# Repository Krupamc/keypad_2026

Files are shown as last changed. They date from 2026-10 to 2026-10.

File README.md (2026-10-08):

# My Linux-looking Macropad
The name is a work in progress I know haha. This is my macropad, a small custom shortcut pad with several layers of shortcuts that are changed through the rotary encoder. Different LEDs light up and the OLED with update with the current layer and appropriate image. I created this in order to increase my productivity and overall workflow of my desk.
---

## Features:
- 128x32 OLED Display for customized layer imagary
- EC11 Rotary encoder to switch between layers.
- 5 Layer LEDs to coordinate with the layers (will activate one by one and change colors; layer 0 has 1 navy blue LEDs, layer 1 has 2 dark blue LEDs).
  - (Colors are customizable) 
- 4 Keys
- 1 Status/Ambient LED
- Being a really cool thing to flex.
---
## PCB:
The PCB (Printed Circuit Board) was created using KiCad. Awesome open source software.
You can open the PCB here:


### Schematic: 

Here is the plan for the PCB laid out with my wiring.

### PCB:


Very cool looking PCB. I added as much silkscreen I could to really sell the terminal-inspired design.

## CAD:

I created a case in Fusion. Excuse how it is not very good/original as it is my first time doing CAD before. I have two parts: the bottom and top case. 
### Bottom Case:
The bottom case is a box with standoffs to hold (on the top-right, and bottom-left) the PCB. M3x16mm screws go through the screw holes on the bottom through the standoffs. The bottom case also has a single foot that has a 40° angle for one inch. (same as my current keyboard to be consistant) The foot has small circle indents for rubber feet in future or hot glue. There is also a USB-C cutout for the microcontroller 

### Top Case:  
This section has extrusions for heat inserts to go (for the screws mentioned before) as well as holes for the OLED, LEDs, keys, and the rotary encoder.




---

## Firmware Functions:
Coded in KMK (Micro-python based keyboard framework). On each layer, a configurable photo, text splash and color (for LEDs) is shown. The number of LEDs active is based on the layer number.

Right now the short cuts include:
- Copy, Paste, Undo, Redo
- CTRL + F, clipboard, File explorer, Screenshots
- Pause unpause, mute discord mic, defen discord, mute pc

Planned to add ones for games I play/other applications later.

---

## BOM:
- 1X Seeed XIAO RP2040
- 1x 0.91" 128x32 OLED Display
- 4x Cherry MX Switches
- 4x DSA Keycaps
- 1x EC11E Rotary encoders
- 6x SK6812 MINI-E LEDs
- 2x M3x16mm screws
- 2x M3x5mx4mm heatset inserts
- 3x Parts for 3D Case (Top, Bottom, and Knob).

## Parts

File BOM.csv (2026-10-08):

Item | Quantity
Seeed XIAO RP2040 | 1
0.91" 128x32 OLED Display | 1
Cherry MX Switches | 4
DSA Keycaps | 4
EC11E Rotary encoders | 1
SK6812 MINI-E LEDs | 6
M3x16mm screws | 2
M3x5mx4mm heatset inserts | 2
Parts for 3D Case (Top, Bottom, and Knob). | 1

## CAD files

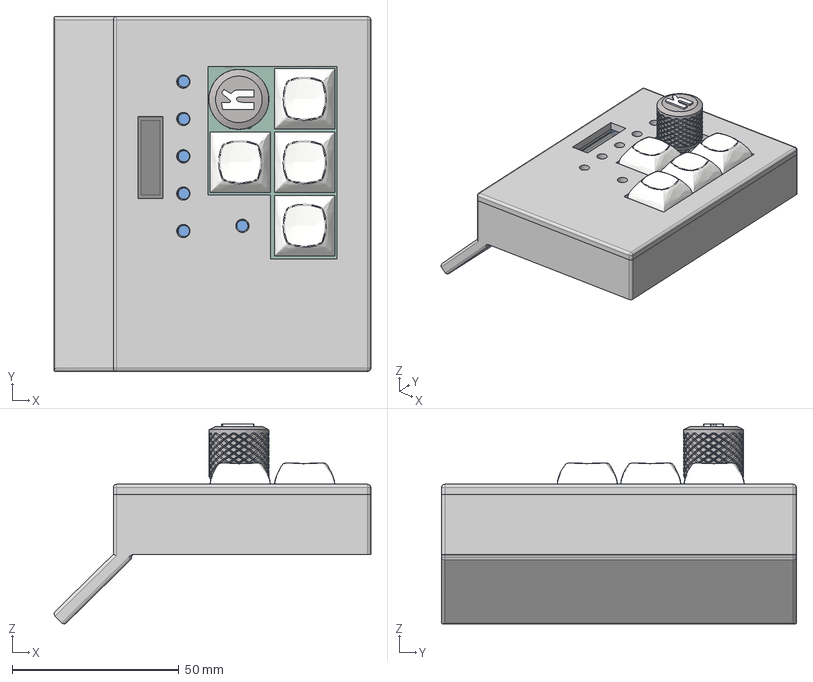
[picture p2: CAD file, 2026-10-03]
CAD/hackpad_full.step
94.9 x 106.3 x 59.8 mm
base v6
type-c v2
smd_button v3
DOUT
DIN
VSS
VDD
smd_button v3(Mirror)
MX Öá °´¼ü¡ä_¨¹ ___¡§1 x 4
MX Öá ÖáÌå¨¢¨¬ _¡§¡é¡§__ x 4
MXÖá ÖáÌå µ×²¿ ¦Ì¡ Á2__Ä¬ÈÏ_¨¢2____¨¨_ x 4
Õë½Å___Ä¬ÈÏ__¨¨ _ x 4
Ðý×ª±àÂëÆ÷
PinHeader_1x04_P254mm_Vertical
hackpad_copper
hackpad_pad
hackpad_via
hackpad_silkscreen
hackpad_silkscreen_1
hackpad_soldermask
hackpad_soldermask_1
hackpad_PCB
LED_WS2812B_PLCC4_50x50mm_P32mm x 6
0.91in oled Module - Board
0.91in OLED - Folded Flush - Without Glass
0603 Capacitor x 9
0603 Resistor x 5
SOT23-3
Diode (SOD-323)
MX Mount v1 x 4
Base
M3x12 SHCS x 2
Keypad
M3 Threaded Insert x 2

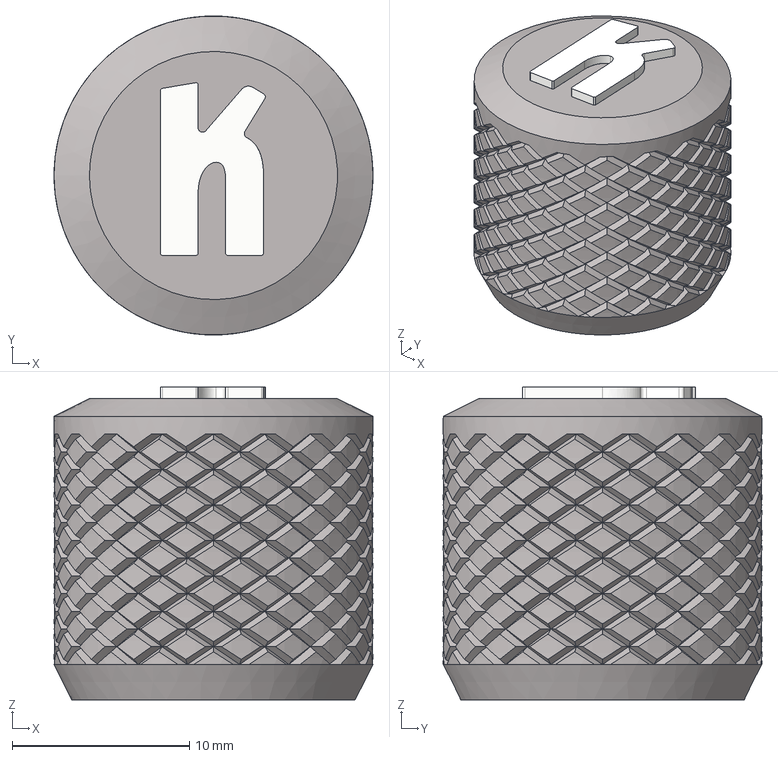
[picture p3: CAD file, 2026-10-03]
production/KNOB.step
18.0 x 18.0 x 17.6 mm
Base
H

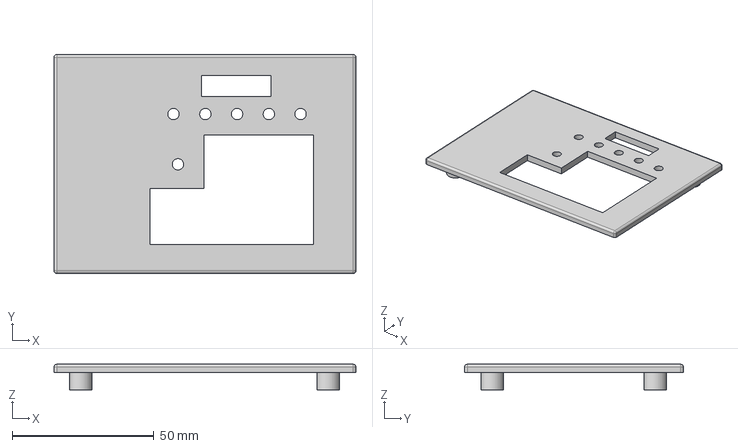
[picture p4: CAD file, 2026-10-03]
production/TOP.step
106.3 x 77.2 x 9.00 mm

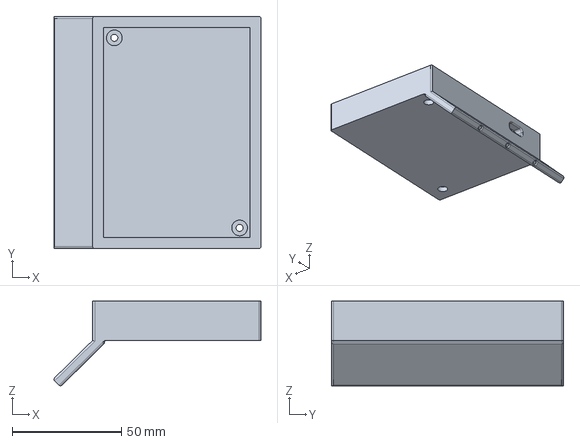
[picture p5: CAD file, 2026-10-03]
production/BOTTOM.step
94.9 x 106.3 x 38.8 mm

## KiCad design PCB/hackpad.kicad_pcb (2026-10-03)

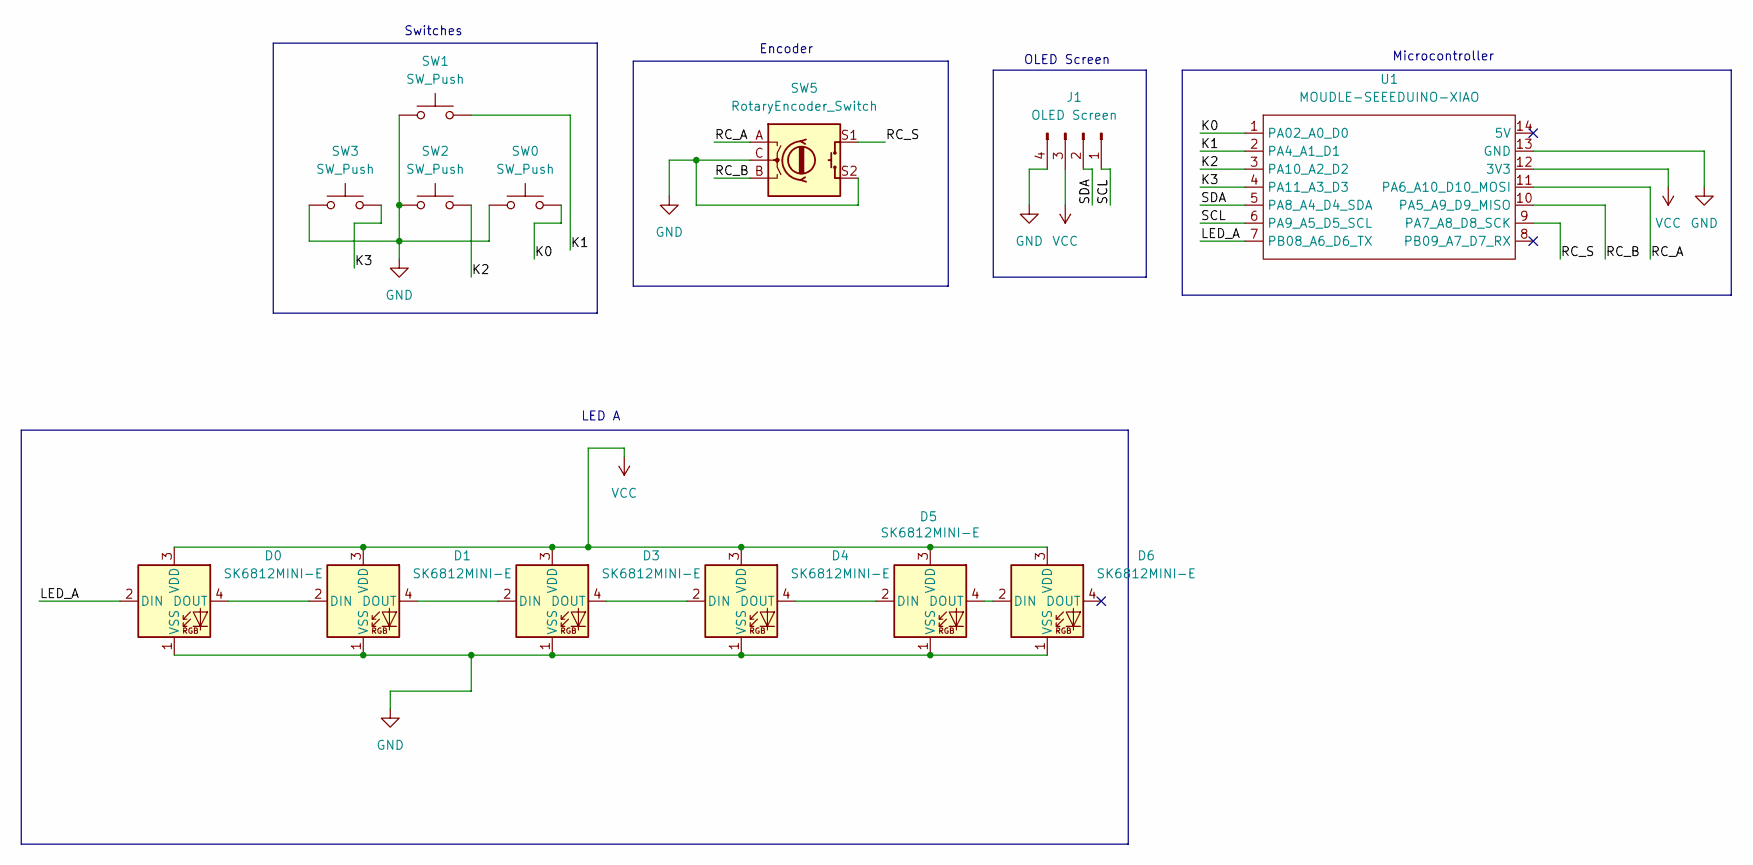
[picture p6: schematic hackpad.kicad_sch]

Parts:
D0, D1, D3, D4, D5, D6: SK6812MINI-E; LED_OPSCO_SK6812_PLCC4_5.0x5.0mm_P3.1mm
J1: OLED Screen; PinHeader_1x04_P2.54mm_Vertical
SW0, SW1, SW2, SW3: SW_Push; SW_Cherry_MX_1.00u_PCB
SW5: RotaryEncoder_Switch; RotaryEncoder_Alps_EC11E-Switch_Vertical_H20mm
U1: MOUDLE-SEEEDUINO-XIAO; XIAO-Generic-Hybrid-14P-2.54-21X17.8MM

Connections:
/K0: SW0.2, U1.1 (PA02_A0_D0)
/K1: SW1.2, U1.2 (PA4_A1_D1)
/K2: SW2.2, U1.3 (PA10_A2_D2)
/K3: SW3.2, U1.4 (PA11_A3_D3)
/LED_A: D0.2 (DIN), U1.7 (PB08_A6_D6_TX)
/RC_A: SW5.A, U1.11 (PA6_A10_D10_MOSI)
/RC_B: SW5.B, U1.10 (PA5_A9_D9_MISO)
/RC_S: SW5.S1, U1.9 (PA7_A8_D8_SCK)
/SCL: J1.1, U1.6 (PA9_A5_D5_SCL)
/SDA: J1.2, U1.5 (PA8_A4_D4_SDA)
GND: D0.1 (VSS), D1.1 (VSS), D3.1 (VSS), D4.1 (VSS), D5.1 (VSS), D6.1 (VSS), J1.4, SW0.1, SW1.1, SW2.1, SW3.1, SW5.C, SW5.S2, U1.13 (GND)
unnamed: D0.4 (DOUT), D1.2 (DIN)
unnamed: D1.4 (DOUT), D3.2 (DIN)
unnamed: D3.4 (DOUT), D4.2 (DIN)
unnamed: D4.4 (DOUT), D5.2 (DIN)
unnamed: D5.4 (DOUT), D6.2 (DIN)
VCC: D0.3 (VDD), D1.3 (VDD), D3.3 (VDD), D4.3 (VDD), D5.3 (VDD), D6.3 (VDD), J1.3, U1.12 (3V3)

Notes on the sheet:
Microcontroller
Switches
OLED Screen
Encoder
LED A

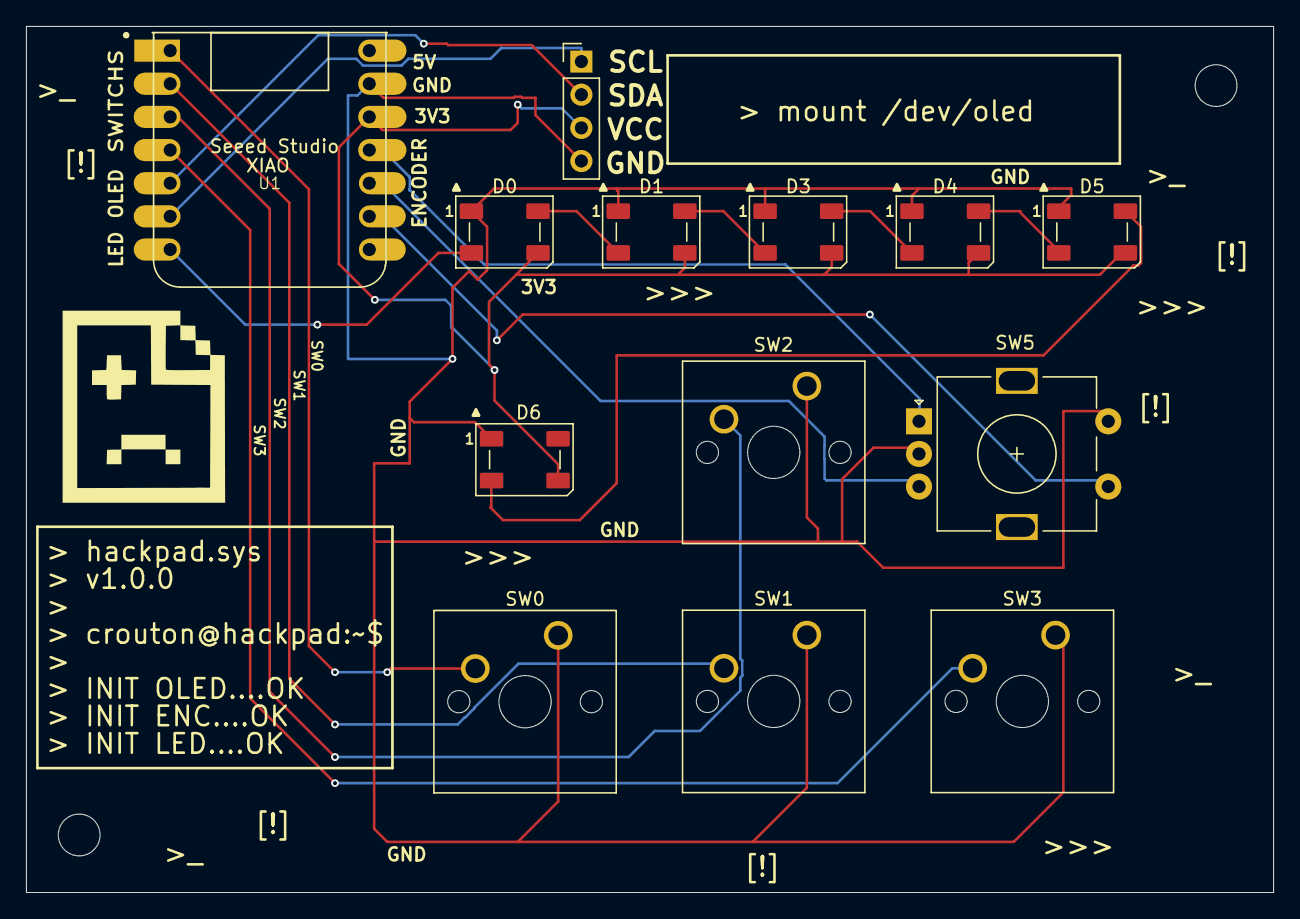
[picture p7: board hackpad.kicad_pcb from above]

Board: 2 copper layers, 95.5 x 66.4 mm, 13 parts (0 on the bottom side), 17 nets.

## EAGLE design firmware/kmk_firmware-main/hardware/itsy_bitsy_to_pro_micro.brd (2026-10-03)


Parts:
FRAME2: FRAME-LETTER; CREATIVE_COMMONS
JP1: HEADER-1X570MIL; 1X05_ROUND_70
JP2, JP4: HEADER-1X14; 1X14_ROUND70
JP3, JP5: M12PTH; 1X12

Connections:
!RESET: JP3.3, JP4.14
+3V3: JP4.13
A0: JP3.5, JP4.10
A1: JP3.6, JP4.9
A2: JP3.7, JP4.8
A3: JP3.8, JP4.7
A4: JP3.9, JP4.6
A5: JP3.10, JP4.5
AREF: JP4.12
D2: JP4.1
D3: JP1.4
D4: JP1.5
D5_5V: JP2.10
D7: JP2.9, JP5.1
D9: JP2.8, JP5.2
D10: JP2.7, JP5.3
D11: JP2.6, JP5.4
D12: JP2.5, JP5.5
D13: JP2.4, JP5.6
EN: JP1.1
GND: JP2.2, JP3.2, JP5.9, JP5.10
MISO: JP4.2
MOSI: JP3.12, JP4.3
RAW_PM: JP3.1
RX_D0: JP2.14, JP5.11
SCK: JP3.11, JP4.4
SCL: JP2.11, JP5.7
SDA: JP2.12, JP5.8
SWCLK: JP1.3
SWDIO: JP1.2
TX_D1: JP2.13, JP5.12
VBAT: JP2.1
VBUS: JP2.3, JP3.4
VHI: JP4.11

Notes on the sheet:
TX0/PD3->TX RX1/PD2->RX GND->GND GND->GND 2/PD1->SDA 3/PD0->SCL 4/PD4->13 5/PC6->12 6/PD7->11 7/PE6->10 8/PB4->9 9/PB5->7
OLD
Raw-> GND->GND RST->RST VCC->USB A3/PF4->A0 A2/PF5->A1 A1/PF6->A2 A0/PF7->A3 15/PB1->A4 14/PB3->A5 16/PB2->SCK 10/PB6->MOSI
Bryan Siepert



Board: 2 copper layers, 35.8 x 20.7 mm, 6 parts (2 on the bottom side), 21 nets.

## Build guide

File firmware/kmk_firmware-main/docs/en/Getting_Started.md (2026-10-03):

# Getting Started
> Life was like a box of chocolates. You never know what you're gonna get.

KMK is a keyboard focused layer that sits on top of [CircuitPython](https://circuitpython.org/). As such, it should work with most [boards that support CircuitPython](https://circuitpython.org/downloads). KMK requires CircuitPython version 7.3 or above.
Known working and recommended devices can be found in the [list of officially supported microcontrollers](Officially_Supported_Microcontrollers.md)

## TL;DR Quick start guide
> To infinity and beyond!
1. [Install CircuitPython version 7.3 or higher on your board](https://learn.adafruit.com/welcome-to-circuitpython/installing-circuitpython). With most boards, it should be as easy as drag and dropping the firmware on the drive
2. Get an up to date [copy of KMK](https://github.com/KMKfw/kmk_firmware/archive/refs/heads/main.zip) from the main branch 
3. Unzip it and copy the KMK folder and the boot.py file at the root of the USB drive corresponding to your board (often appearing as CIRCUITPY)
4. Create a new *code.py* or *main.py* file in the same root directory (same level as boot.py) with the example content hereunder: 

***IMPORTANT:*** adapt the GP0 / GP1 pins to your specific board !

```
print("Starting")

import board

from kmk.kmk_keyboard import KMKKeyboard
from kmk.keys import KC
from kmk.scanners import DiodeOrientation

keyboard = KMKKeyboard()

keyboard.col_pins = (board.GP0,)
keyboard.row_pins = (board.GP1,)
keyboard.diode_orientation = DiodeOrientation.COL2ROW

keyboard.keymap = [
    [KC.A,]
]

if __name__ == '__main__':
    keyboard.go()
```

5. With a wire / paperclip / whatever, connect the pins you selected for col_pin and row_pin together.

feather and keeboar example pins


6. If it prints the letter "a" (or a "Q" or ... depending on your keyboard layout), you're done!

## Now that you're up and running, you may want to go further...
> This is your last chance. After this, there is no turning back. You take the blue pill—the story ends, you wake up in your bed and believe whatever you want to believe. You take the red pill—you stay in Wonderland, and I show you how deep the rabbit hole goes. Remember: all I'm offering is the truth. Nothing more.

### You're extremely lucky and you have a fully supported keyboard
If your keyboard and microcontroller are officially supported, simply visit the page for your files, and dropping them on the root of the "flash drive".
Those pages can be found in the repositories [boards folder](https://github.com/KMKfw/kmk_firmware/tree/master/boards).
You will need the `kb.py` and `main.py`. If you need more detailed instructions on how to customize the configuration settings and key mappings, please refer to the [config and keymap](config_and_keymap.md) documentation.

### You've got another, maybe DIY, board and want to customize KMK for it  
First, be sure to understand how your device work, and particularly its specific matrix configuration. You can have a look at [how key matrices work](http://pcbheaven.com/wikipages/How_Key_Matrices_Works/) or read the [guide](https://docs.qmk.fm/#/hand_wire) provided by the QMK team for handwired keyboards
Once you've got the gist of it:
- To start customizing your `code.py`/`main.py` file, please refer to the [config and keymap](config_and_keymap.md) and [keys](keys.md) files respectively, which provide detailed instructions on how to modify the configuration settings and key mappings.
- There's a [reference](keycodes.md) of the available keycodes
- [International](international.md) extension adds keys for non US layouts and [Media Keys](media_keys.md) adds keys for ... media

And to go even further:
- [Macros](macros.md) are used for sending multiple keystrokes in a single action
- [Layers](layers.md) can transform the whole way your keyboard is behaving with a single touch
- [HoldTap](holdtap.md) allow you to customize the way a key behaves whether it is tapped or hold, and [TapDance](tapdance.md) depending on the number of times it is pressed

Want to have fun features such as RGB, split keyboards and more? Check out what builtin [modules](modules.md) and [extensions](extensions.md) can do!
You can also get ideas from the various [user examples](https://github.com/KMKfw/kmk_firmware/tree/master/user_keymaps) that we provide and dig into our [documentation](README.md).

### Pre-compiling KMK for faster boot times or microcontrollers with limited flash

There are two options:
1. To compile KMK yourself you'll need to download and install the [compatible mpy-cross](https://adafruit-circuit-python.s3.amazonaws.com/index.html?prefix=bin/mpy-cross/)
  for your Operating System. Don't forget to add it to your PATH, test by running `mpy-cross` from a shell (Powershell, Bash, Fish, etc). Once that's set up, run either `make compile` (if you have `make`) or `python util/compile.py`to generate the `.mpy` versions of KMK files. Then copy the whole compiled `kmk/` directory to your keyboard.

There are even more compile and copy make targets.
Power user can compile KMK and additional libraries, and then load the bytecode and keyboard code
onto a keyboard in one go:
```sh
make compile copy-compiled copy-board MPY_SOURCES='kmk/ lib/' BOARD='boards/someboard' MOUNTPOINT='/media/user/someboard'
```

2. To download a pre-compiled KMK go to [Actions > Build on the KMK GitHub project page](https://github.com/KMKfw/kmk_firmware/actions/workflows/compile.yml),
  click on the latest build, and you'll find the download link at the bottom of the page under Artifacts. Unzip the download and place the contents in the `kmk/` directory on your keyboard.

On certain microcontrollers that will still not be enough of a size reduction to
fit all of KMK onto the flash (nice!nano for example).
You can remove any optional parts of KMK you aren't using.
Start by skipping `kmk/extensions`, `kmk/modules`, and `kmk/quickpin` and adding in only the files under those paths used in your keyboard (i.e. files that are imported in your `main.py` or `kb.py`).

## Additional help and support
> Roads? Where we're going we don't need roads.

In case you need it, debugging help can be found on the [debugging](debugging.md) page.

For asynchronous support and chatter about KMK, [join our Zulip
community](https://kmkfw.zulipchat.com)!

If you ask for help in chat or open a bug report, if possible
make sure your copy of KMK is up-to-date.
In particular, swing by the Zulip chat *before* opening a GitHub Issue about
configuration, documentation, etc. concerns.

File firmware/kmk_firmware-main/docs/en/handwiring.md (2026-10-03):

# Handwire keyboards
This guide will not talk about the physical wiring. Check out our 
[recommended microcontrollers](Officially_Supported_Microcontrollers.md) and 
follow this amazing [hand wiring guide](https://docs.qmk.fm/#/hand_wire). That 
guide can be followed until you are setting up the firmware. After wiring the 
keyboard, you can refer to our [porting guide](porting_to_kmk.md)

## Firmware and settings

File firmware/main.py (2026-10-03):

import board
import busio
import displayio
import terminalio
import neopixel
import adafruit_imageload

from adafruit_display_text import label
from adafruit_displayio_ssd1306 import SSD1306
from kmk.kmk_keyboard import KMKKeyboard
from kmk.keys import KC
from kmk.modules.encoder import EncoderHandler
from kmk.scanners import DiodeOrientation

displayio.release_displays()

# Layer Colors:
layer0 = (29, 45, 68)
layer1 = (62, 92, 118)
layer2 = (115, 140, 171)
layer3 = (255, 255, 255)
layer4 = (255, 255, 255)

# Layer Icons
ilayer0 = "/images/paste_inverse.bmp"
ilayer1 = "/images/folder.bmp"
ilayer2 = "/images/mic1.bmp"
ilayer3 = "/images/error.bmp"
ilayer4 = "/images/error.bmp"

# LEDs (SK6812)

led_num = 6 # Number of leds used
pixels = neopixel.NeoPixel(board.D6, led_num, auto_write = True)

# Turn off all Leds on boot
pixels.fill((0, 0, 0))



# OLED Setup
i2c = busio.I2C(scl = board.D5, sda = board.D4)
display_bus = displayio.I2CDisplay(i2c, device_address=0x3c) # Change if different adress

W = 128
H = 32

display = SSD1306(display_bus, width = W, height = H)

# Splash Group
splash = displayio.Group()
display.show(splash)

# Text Setup
text_area = label.Label(
    terminalio.FONT,
    text = "Test?",
    color = 0xFFFFFF,
    x = 0,
    y = H // 2
)

# Image Setup

# Example image
bitmap, palette = adafruit_imageload.load(
    "/images/paste_inverse.bmp",
    bitmap = displayio.Bitmap,
    palette = displayio.Palette
)

icon = displayio.TileGrid(
    bitmap,
    pixel_shader=palette,
    x=0,
    y=0
)

# Append Images
splash.append(text_area)
splash.append(icon)

# Keyboard Setup

keyboard = KMKKeyboard()

def before_matrix_scan(kbd):
    layer_update(kbd)

keyboard.before_matrix_scan = before_matrix_scan

#Indivdual GPIO for each key:
keyboard.col_pins = (board.D0, board.D1, board.D2, board.D3) # Each COLOMN individual gpio
keyboard.row_pins = (board.D7,) # The "row" gpio; uses a random free gpio
keyboard.diode_orientation = DiodeOrientation.COL2ROW

# Encoder Setup
encoder_handler = EncoderHandler()
keyboard.modules.append(encoder_handler)

encoder_handler.pins = (
    (board.D8, board.D9, board.D10, False)
)

encoder_handler.map = [
    # Layer 0 - #-0-1
    [
        (KC.TO(1), KC.NO, KC.P) #REPLACE THE PUSH
    ],

    # Layer 1 - 0-1-2
    [
        (KC.TO(2), KC.TO(0), KC.P)
    ],
    
    # Layer 2 - 1-2-3
    [
        (KC.TO(3), KC.TO(1), KC.P)
    ],

    # Layer 3 - 2-3-4 (Layers after this are extra space for expansion for gaming, productivity, etc)
    [
        (KC.TO(4), KC.TO(2), KC.P)
    ],

    # Layer 4 - 3-4-#
    [
        (KC.NO, KC.TO(3), KC.P)
    ]
    
]


# Keymap
keyboard.keymap = [
    #layer 0
    [KC.COPY, KC.PASTE, KC.REDO, KC.UNDO],

    #layer 1 - (I already have a stero sound system so no need for volume wheel)
    [KC.LCTL(KC.F), KC.RWIN(KC.V), KC.RWIN(KC.E), KC.RWIN(KC.LSFT(KC.S))], #CTRL + F, clipboard, File explorer, Screenshots

    #layer 2
    [KC.MEDIA_PLAY_PAUSE, KC.LCTL(KC.LSFT(KC.M)), KC.LCTL(KC.LSFT(KC.B)), KC.MUTE], # Pause unpause, mute discord mic, defen discord, mute pc

    #ETC - MORE WHEN I FEEL LIKE IT :D

    #layer 3
    [KC.NO, KC.NO, KC.NO, KC.NO]

    #layer 4
    [KC.NO, KC.NO, KC.NO, KC.NO]

]


# Menu!

# Check what layer we are on:
def what_layer(keyboard):
    if not keyboard.active_layers:
        return 0
    return keyboard.active_layers[-1]

# Turn the layer led on and change the colors:
def layer_led(layer):
    pixels.fill((0, 0, 0))

    if layer == 0:
        pixels[0] = layer0
    
    elif layer == 1:
        pixels[0] = layer1
        pixels[1] = layer1

    elif layer == 2:
        pixels[0] = layer2
        pixels[1] = layer2
        pixels[2] = layer2
    
    elif layer == 3:
        pixels[0] = layer3
        pixels[1] = layer3
        pixels[2] = layer3
        pixels[3] = layer3
    
    else:
        pixels[0] = layer4
        pixels[1] = layer4
        pixels[2] = layer4
        pixels[3] = layer4
        pixels[4] = layer4

# Preload images
loaded_icons = {}
def preload_icon(filename):
    bitmap, palette = adafruit_imageload.load(
        filename,
        bitmap=displayio.Bitmap,
        palette=displayio.Palette
    )
    loaded_icons[filename] = (bitmap, palette)

# Preload images to Ram
preload_icon(ilayer0)
preload_icon(ilayer1)
preload_icon(ilayer2)
preload_icon(ilayer3)
preload_icon(ilayer4)

# Update Screen
def layer_screen(layer):
    if layer == 0:
        text_area.text = f"Copy\nPaste\nRedo\nUndo"
        set_icon(ilayer0, 99, 0)

    elif layer == 1:
        text_area.text = f"Find\nClip\nFiles\nShot"
        set_icon(ilayer1, 97, 1)
    
    elif layer == 2:
        text_area.text = f"Pause\n Mute\nDefen\n Mute PC"
        set_icon(ilayer2, 97, 0)

    elif layer == 3:
        text_area.text = f"Woah...\nNothing\nHere"
        set_icon(ilayer3, 1, 0)
    
    else:
        text_area.text = f"Woah...\nNothing\nHere"
        set_icon(ilayer4, 1, 0)

def set_icon(filename, x_cord, y_cord):
    bitmap, palette = loaded_icons[filename]
    new_icon = displayio.TileGrid(
        bitmap,
        pixel_shader=palette,
        x = x_cord,
        y = y_cord
    )

    splash[1] = new_icon

# Update everything
def layer_update(keyboard):
    global last_layer
    layer = what_layer(keyboard)
    if layer != last_layer:
        last_layer = layer
        layer_led(layer)
        layer_screen(layer)

last_layer = -1
layer_update(keyboard)

if __name__ == "__main__":
    keyboard.go()

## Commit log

2026-10-03 Inital Commit with Fully Completed Project ;-;
    [BOTTOM.step, KNOB.step, TOP.step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]
2026-10-08 Add Bom.csv
    [BOM.csv]
2026-10-08 Add PCB button view

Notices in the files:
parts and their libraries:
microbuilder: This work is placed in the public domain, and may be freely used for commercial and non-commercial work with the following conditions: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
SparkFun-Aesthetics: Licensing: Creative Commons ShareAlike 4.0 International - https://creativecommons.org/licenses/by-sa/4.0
